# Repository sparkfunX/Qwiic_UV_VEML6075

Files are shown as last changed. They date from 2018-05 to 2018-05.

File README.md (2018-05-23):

SparkFun UV Sensor (Qwiic) - VEML6075
========================================

SparkFun UV Sensor (Qwiic) - VEML6075

[*SparkX UV Sensor (Qwiic) - VEML6075 (SPX-14748)*](https://www.sparkfun.com/products/14748)

Need to apply some sunscreen? SPF 15? SPF 50? SPF 5000? It's time to consult the Qwiic VEML6075 UV sensor!

The **VEML6075** can detect the intensity of UVA (~365nm) and UVB (~330nm) waves. With a quick calculation, those values can be used to generate a standardized **UV index** -- a value from 0 to 11+ which indicates the relative strength of UV irradiance. Seeing a UVI above 6-7? Find some shade, or slather on that sun screen!

The VEML6075 features a simple I<sup>2</sup>C interface, so we stuck it on a [Qwiic](https://www.sparkfun.com/qwiic)-compatible board. This board requires no voltage translation, no figuring out which pin is SDA or SCL; just plug it in and go!

Check out our [SparkFun_VEML6075_Arduino_Library repo](https://github.com/sparkfun/SparkFun_VEML6075_Arduino_Library) for a simple Arduino library -- there's example code to configure the sensor, read its UVA and UVB outputs, and generate a UV index output. Stay safe out there this summer!

SparkFun labored with love to create this code. Feel like supporting open source hardware? 
Buy a [breakout board](https://www.sparkfun.com/products/14748) from SparkFun!

Repository Contents
-------------------

* **/Documents** - Datasheets
* **/Hardware** - Eagle design files (.brd, .sch)

License Information
-------------------

This product is _**open source**_! 

If you have any questions or concerns on licensing, please contact techsupport@sparkfun.com.

Please use, reuse, and modify these files as you see fit. Please maintain attribution to SparkFun Electronics and release any derivative under the same license.

Distributed as-is; no warranty is given.

- Your friends at SparkFun.

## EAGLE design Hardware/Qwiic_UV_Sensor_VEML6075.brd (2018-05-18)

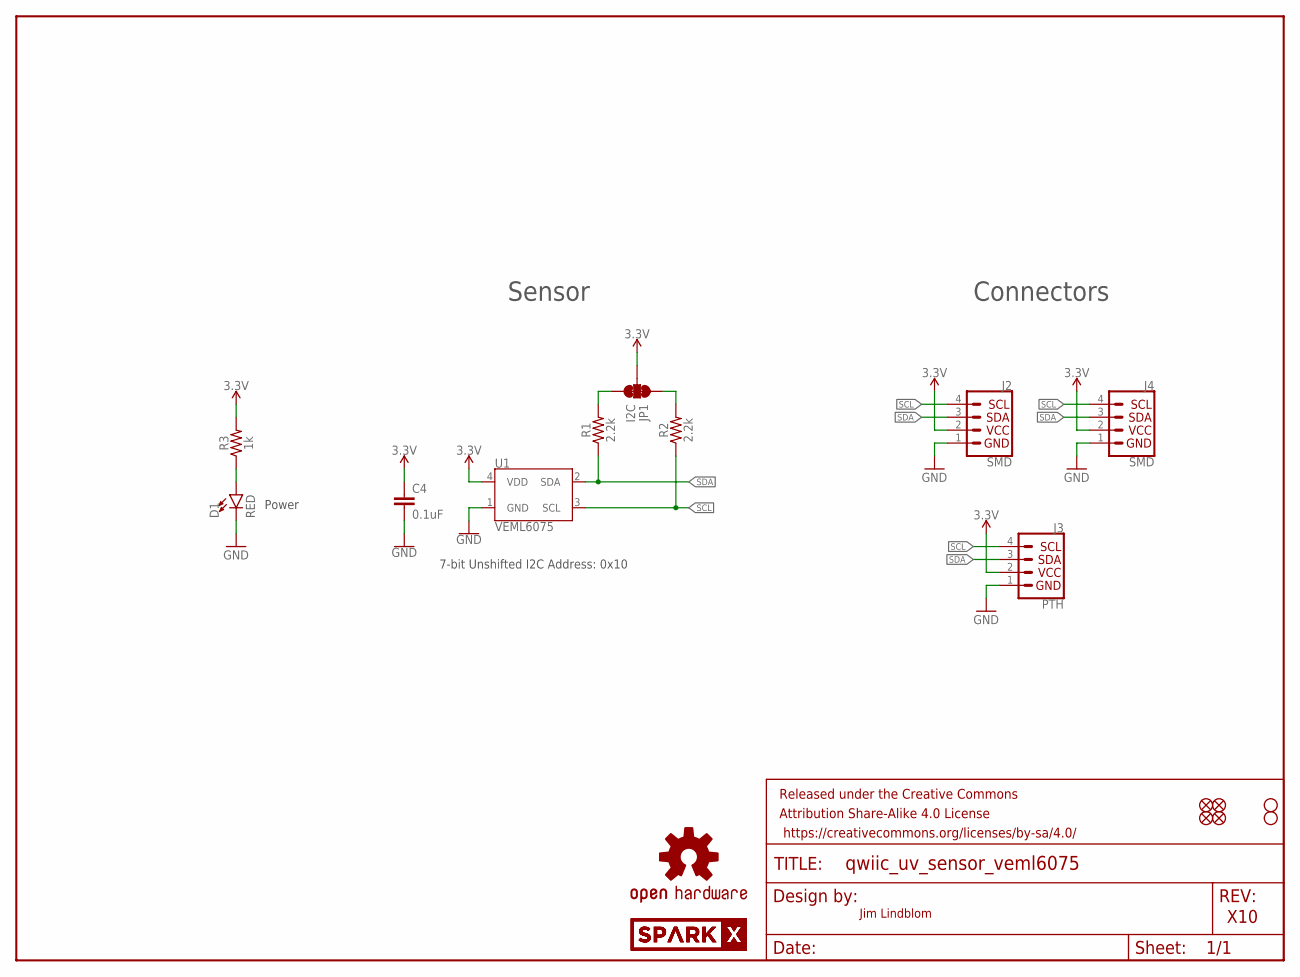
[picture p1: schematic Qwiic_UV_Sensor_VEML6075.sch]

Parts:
C4: 0.1uF; 0603
D1: RED; LED-0603
FRAME1: FRAME-LETTER; CREATIVE_COMMONS
J2, J4: SMD; 1X04_1MM_RA
J3: PTH; 1X04_NO_SILK
JP1: I2C; SMT-JUMPER_3_2-NC_TRACE_SILK
JP2, JP5, JP6, JP7: FIDUCIALUFIDUCIAL; MICRO-FIDUCIAL
JP3, JP4: STAND-OFF
LOGO1: OSHW-LOGOMINI; OSHW-LOGO-MINI
R1, R2: 2.2k; 0603
R3: 1k; 0603
U1: VEML6075; VEML6075_A3OP
U$1, U$2: SPARKX-LOGO4; SPARKX-MEDIUM

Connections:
3.3V: C4.1, J2.2 (VCC), J3.2 (VCC), J4.2 (VCC), JP1.2, R3.2, U1.4 (VDD)
GND: C4.2, D1.C, J2.1 (GND), J3.1 (GND), J4.1 (GND), U1.1 (GND)
unnamed: D1.A, R3.1
unnamed: JP1.3, R1.2
unnamed: JP1.1, R2.2
SCL: J2.4 (SCL), J3.4 (SCL), J4.4 (SCL), R2.1, U1.3 (SCL)
SDA: J2.3 (SDA), J3.3 (SDA), J4.3 (SDA), R1.1, U1.2 (SDA)

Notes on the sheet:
Power
7-bit Unshifted I2C Address: 0x10
X10
Sensor
Connectors
Jim Lindblom

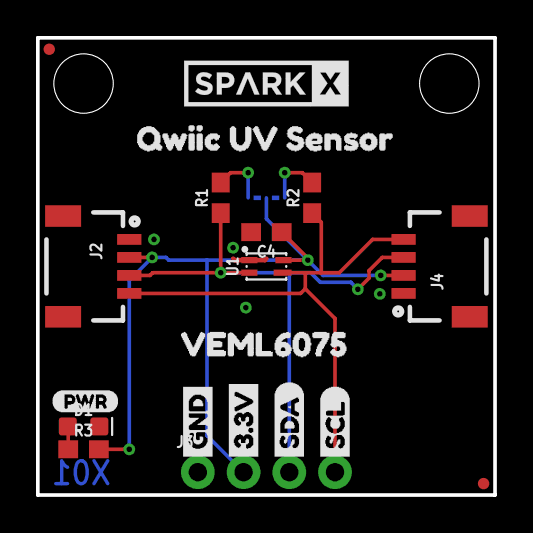
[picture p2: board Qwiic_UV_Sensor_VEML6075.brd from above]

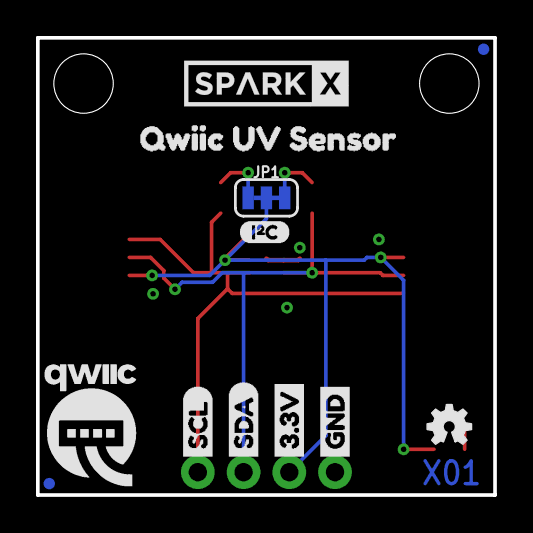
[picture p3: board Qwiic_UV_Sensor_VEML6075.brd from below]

Board: 2 copper layers, 25.4 x 25.4 mm, 34 parts (12 on the bottom side), 7 nets.

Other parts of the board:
U$3: QWIIC-LOGO-MEDIUM
U$4, U$22: GND1
U$5, U$11: QWIIC_UV_SENSOR1
U$6: _VEML60750
U$7, U$21: 3#3V2
U$8, U$27: SDA8
U$9, U$26: SCL9
U$10: I_SUPER2_C-()-03
U$16: PWR-()-03

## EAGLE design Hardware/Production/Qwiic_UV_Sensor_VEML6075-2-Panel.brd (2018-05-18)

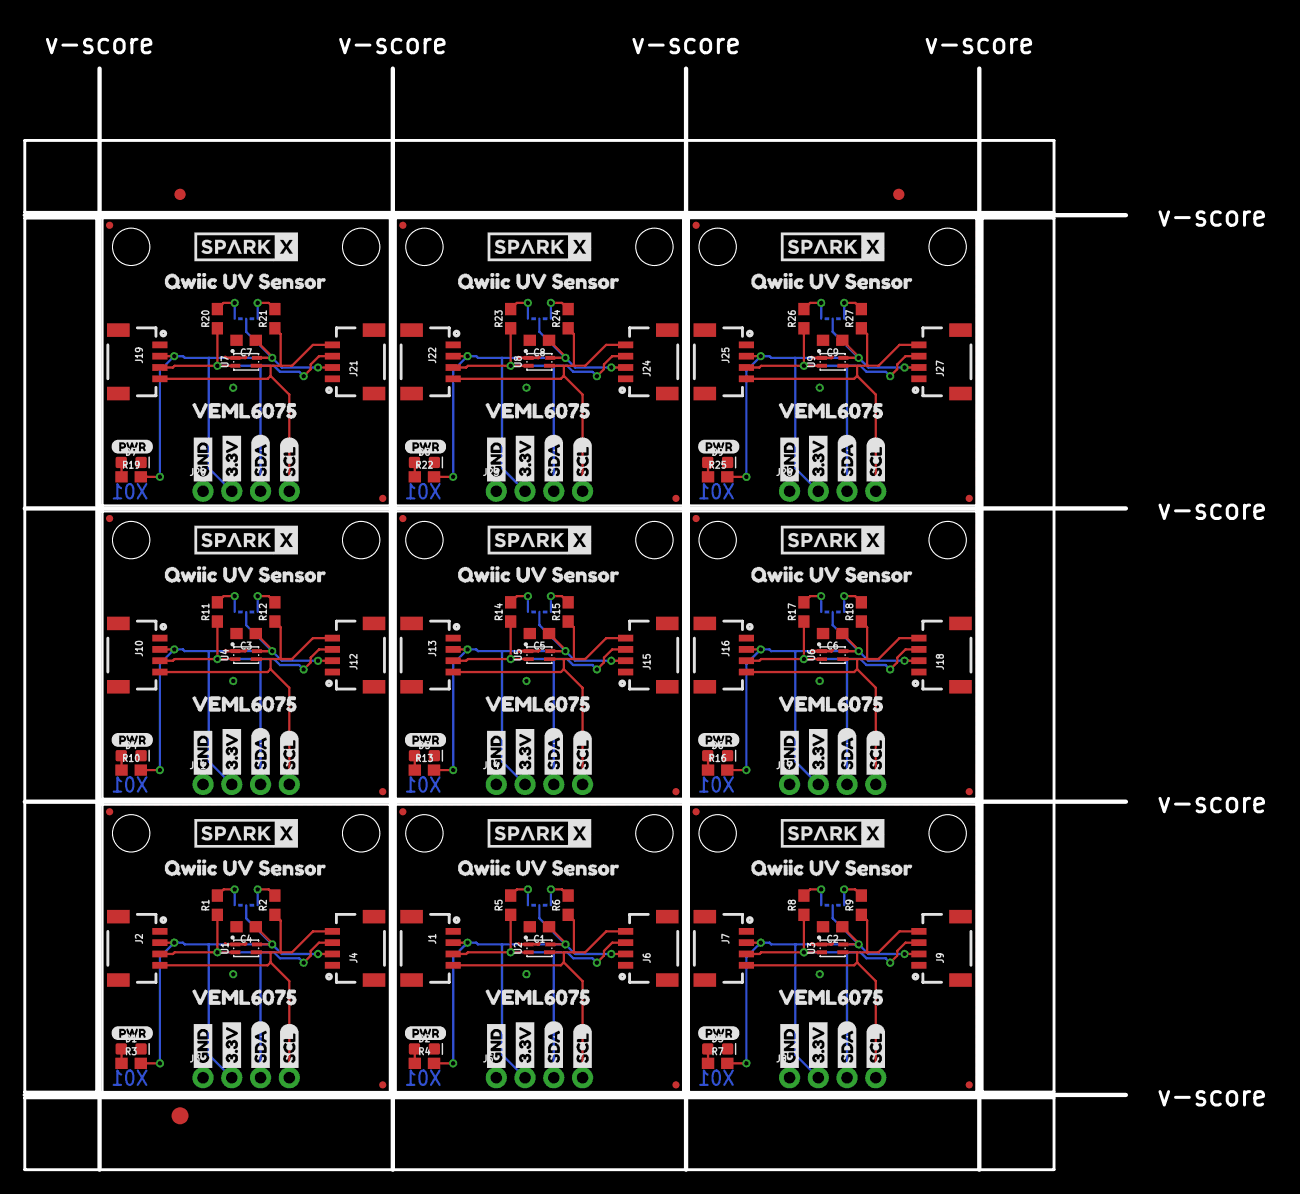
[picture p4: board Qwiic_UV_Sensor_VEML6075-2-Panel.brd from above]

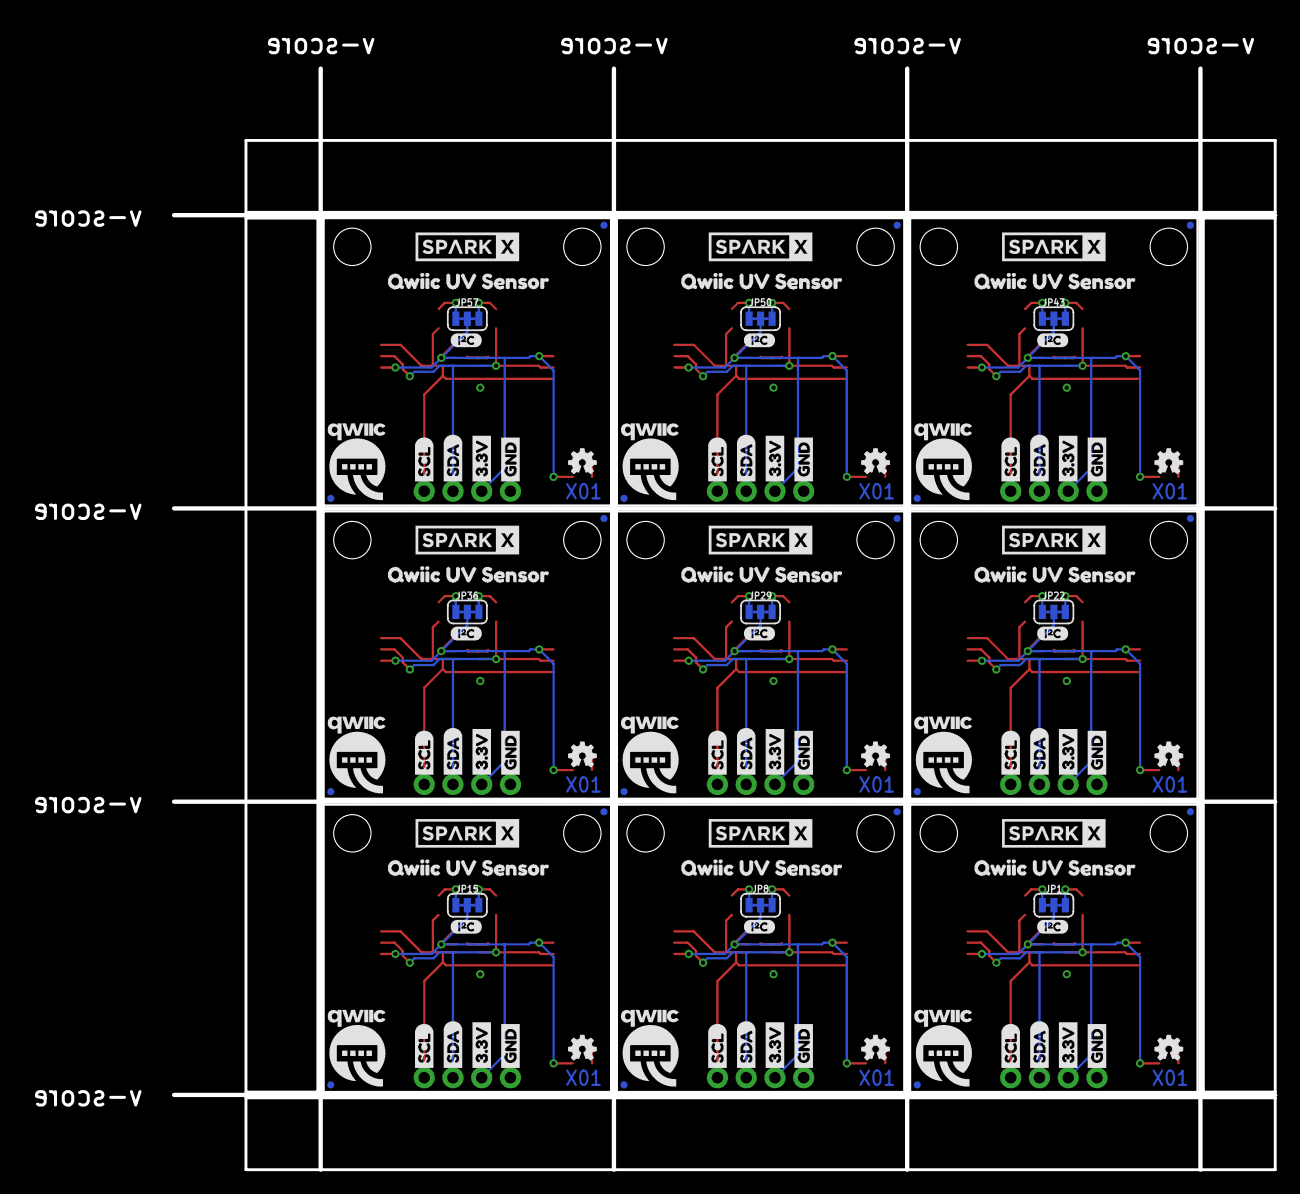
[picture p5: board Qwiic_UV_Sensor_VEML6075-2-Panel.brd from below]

Board: 2 copper layers, 97.3 x 97.3 mm, 306 parts (108 on the bottom side), 63 nets.

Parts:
C1, C2, C3, C4, C5, C6, C7, C8, C9: 0.1uF; 0603
D1, D2, D3, D4, D5, D6, D7, D8, D9: RED; LED-0603
E$1, E$2: FIDUCIAL-1X2
E$3: FIDUCIAL-1.5X3
FRAME1, FRAME2, FRAME3, FRAME4, FRAME5, FRAME6: FRAME-LETTER; CREATIVE_COMMONS
J1, J2, J4, J6, J7, J9, J10, J12, J13, J15, J16, J18, J19, J21, J22, J24, J25, J27: SMD; 1X04_1MM_RA
J3, J5, J8, J11, J14, J17, J20, J23, J26: PTH; 1X04_NO_SILK
JP1, JP8, JP15, JP22, JP29, JP36, JP43, JP50, JP57: I2C; SMT-JUMPER_3_2-NC_TRACE_SILK
JP2, JP5, JP6, JP7, JP11, JP12, JP13, JP14, JP18, JP19, JP20, JP21, JP25, JP26, JP27, JP28, JP32, JP33, JP34, JP35, JP39, JP40, JP41, JP42, JP46, JP47, JP48, JP49, JP53, JP54, JP55, JP56, JP60, JP61, JP62, JP63: FIDUCIALUFIDUCIAL; MICRO-FIDUCIAL
JP3, JP4, JP9, JP10, JP16, JP17, JP23, JP24, JP30, JP31, JP37, JP38, JP44, JP45, JP51, JP52, JP58, JP59: STAND-OFF
LOGO1, LOGO2, LOGO3, LOGO4, LOGO5, LOGO6, LOGO7, LOGO8, LOGO9: OSHW-LOGOMINI; OSHW-LOGO-MINI
R1, R2, R5, R6, R8, R9, R11, R12, R14, R15, R17, R18, R20, R21, R23, R24, R26, R27: 2.2k; 0603
R3, R4, R7, R10, R13, R16, R19, R22, R25: 1k; 0603
U1, U2, U3, U4, U5, U6, U7, U8, U9: VEML6075; VEML6075_A3OP
U$1, U$2, U$12, U$13, U$33, U$34, U$49, U$50, U$65, U$66, U$81, U$82, U$97, U$98, U$113, U$114, U$129, U$130: SPARKX-LOGO4; SPARKX-MEDIUM
U$3, U$14, U$35, U$51, U$67, U$83, U$99, U$115, U$131: QWIIC-LOGO-MEDIUM
U$4, U$17, U$22, U$28, U$37, U$44, U$53, U$60, U$69, U$76, U$85, U$92, U$101, U$108, U$117, U$124, U$133, U$140: GND1
U$5, U$11, U$25, U$32, U$43, U$48, U$59, U$64, U$75, U$80, U$91, U$96, U$107, U$112, U$123, U$128, U$139, U$144: QWIIC_UV_SENSOR1
U$6, U$24, U$42, U$58, U$74, U$90, U$106, U$122, U$138: _VEML60750
U$7, U$15, U$21, U$29, U$36, U$45, U$52, U$61, U$68, U$77, U$84, U$93, U$100, U$109, U$116, U$125, U$132, U$141: 3#3V2
U$8, U$19, U$27, U$30, U$39, U$46, U$55, U$62, U$71, U$78, U$87, U$94, U$103, U$110, U$119, U$126, U$135, U$142: SDA8
U$9, U$18, U$26, U$31, U$38, U$47, U$54, U$63, U$70, U$79, U$86, U$95, U$102, U$111, U$118, U$127, U$134, U$143: SCL9
U$10, U$20, U$40, U$56, U$72, U$88, U$104, U$120, U$136: I_SUPER2_C-()-03
U$16, U$23, U$41, U$57, U$73, U$89, U$105, U$121, U$137: PWR-()-03

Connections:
3.3V: C4.1, J2.2, J3.2, J4.2, JP1.2, R3.2, U1.4
3.3V1: C1.1, J1.2, J5.2, J6.2, JP8.2, R4.2, U2.4
3.3V2: C2.1, J7.2, J8.2, J9.2, JP15.2, R7.2, U3.4
3.3V3: C3.1, J10.2, J11.2, J12.2, JP22.2, R10.2, U4.4
3.3V4: C5.1, J13.2, J14.2, J15.2, JP29.2, R13.2, U5.4
3.3V5: C6.1, J16.2, J17.2, J18.2, JP36.2, R16.2, U6.4
3.3V6: C7.1, J19.2, J20.2, J21.2, JP43.2, R19.2, U7.4
3.3V7: C8.1, J22.2, J23.2, J24.2, JP50.2, R22.2, U8.4
3.3V8: C9.1, J25.2, J26.2, J27.2, JP57.2, R25.2, U9.4
GND: C4.2, D1.C, J2.1, J3.1, J4.1, U1.1
GND1: C1.2, D2.C, J1.1, J5.1, J6.1, U2.1
GND2: C2.2, D3.C, J7.1, J8.1, J9.1, U3.1
GND3: C3.2, D4.C, J10.1, J11.1, J12.1, U4.1
GND4: C5.2, D5.C, J13.1, J14.1, J15.1, U5.1
GND5: C6.2, D6.C, J16.1, J17.1, J18.1, U6.1
GND6: C7.2, D7.C, J19.1, J20.1, J21.1, U7.1
GND7: C8.2, D8.C, J22.1, J23.1, J24.1, U8.1
GND8: C9.2, D9.C, J25.1, J26.1, J27.1, U9.1
unnamed: D2.A, R4.1
unnamed: JP8.3, R5.2
unnamed: D1.A, R3.1
unnamed: JP1.3, R1.2
unnamed: JP1.1, R2.2
unnamed: JP8.1, R6.2
unnamed: D3.A, R7.1
unnamed: JP15.3, R8.2
unnamed: JP15.1, R9.2
unnamed: D4.A, R10.1
unnamed: JP22.3, R11.2
unnamed: JP22.1, R12.2
unnamed: D5.A, R13.1
unnamed: JP29.3, R14.2
unnamed: JP29.1, R15.2
unnamed: D6.A, R16.1
unnamed: JP36.3, R17.2
unnamed: JP36.1, R18.2
unnamed: D7.A, R19.1
unnamed: JP43.3, R20.2
unnamed: JP43.1, R21.2
unnamed: D8.A, R22.1
unnamed: JP50.3, R23.2
unnamed: JP50.1, R24.2
unnamed: D9.A, R25.1
unnamed: JP57.3, R26.2
unnamed: JP57.1, R27.2
SCL: J2.4, J3.4, J4.4, R2.1, U1.3
SCL1: J1.4, J5.4, J6.4, R6.1, U2.3
SCL2: J7.4, J8.4, J9.4, R9.1, U3.3
SCL3: J10.4, J11.4, J12.4, R12.1, U4.3
SCL4: J13.4, J14.4, J15.4, R15.1, U5.3
SCL5: J16.4, J17.4, J18.4, R18.1, U6.3
SCL6: J19.4, J20.4, J21.4, R21.1, U7.3
SCL7: J22.4, J23.4, J24.4, R24.1, U8.3
SCL8: J25.4, J26.4, J27.4, R27.1, U9.3
SDA: J2.3, J3.3, J4.3, R1.1, U1.2
SDA1: J1.3, J5.3, J6.3, R5.1, U2.2
SDA2: J7.3, J8.3, J9.3, R8.1, U3.2
SDA3: J10.3, J11.3, J12.3, R11.1, U4.2
SDA4: J13.3, J14.3, J15.3, R14.1, U5.2
SDA5: J16.3, J17.3, J18.3, R17.1, U6.2
SDA6: J19.3, J20.3, J21.3, R20.1, U7.2
SDA7: J22.3, J23.3, J24.3, R23.1, U8.2
SDA8: J25.3, J26.3, J27.3, R26.1, U9.2

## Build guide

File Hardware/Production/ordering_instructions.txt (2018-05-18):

panel size, 91x91mm
PCB thickness, 1.6mm
number of layers, 2
soldermask color, Black
silkscreen color, White
oz copper, 1oz
finish, HASL lead free
stencils, top
pcs per panel, 9

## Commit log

2018-05-18 Initial commit of hardware.
    [Qwiic_UV_Sensor_VEML6075.brd, Qwiic_UV_Sensor_VEML6075.sch]
2018-05-18 Initial commit of production panel.
    [Qwiic_UV_Sensor_VEML6075-2-Panel.GBL, Qwiic_UV_Sensor_VEML6075-2-Panel.GBO, Qwiic_UV_Sensor_VEML6075-2-Panel.GBS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]
2018-05-18 Adding sensor documentation.

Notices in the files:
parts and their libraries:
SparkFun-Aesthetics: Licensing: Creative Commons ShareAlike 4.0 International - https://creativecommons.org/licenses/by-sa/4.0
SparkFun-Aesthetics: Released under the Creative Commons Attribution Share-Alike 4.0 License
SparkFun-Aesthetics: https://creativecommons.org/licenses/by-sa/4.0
